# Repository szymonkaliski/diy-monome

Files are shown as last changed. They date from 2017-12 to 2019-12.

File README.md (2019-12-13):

# DIY Monome

This repo contains *some* tools for building and running DIY version of [monome](https://monome.org/) 16x8 / 8x8 grid, that's *mostly* compatible with existing monome patches and software.

There are actually three projects in this repo:
- **Neonome128** based on [Adafruit NeoTrellis boards](https://www.adafruit.com/product/3954)
- **Sparknome** which is based on four [Sparkfun PCBs](https://www.sparkfun.com/products/8033)
- **Trellinome** based on four [Adafruit Trellis boards](https://www.adafruit.com/product/1616)

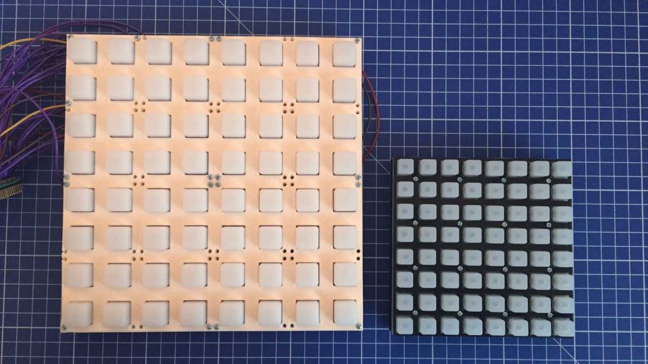
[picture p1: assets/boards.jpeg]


**Sparknome** on right, **Trellinome** on left.

These boards are not a replacement for official monome build (which is much nicer hardware), but just a DIY project.

## Neonome128

Neonome128 was built using Teensy 3.2. Build was similar to Trellinome, and I followed the official guide for soldering the boards together.

The Arduino code to drive the display is in [Neonome128](Neonome128) folder.

## Sparknome

Sparknome is based on Arduino Mega 2560 due to huge amount of digital pins used (that could be fixed with multiplexer though). I followed official [assembly guide](https://learn.sparkfun.com/tutorials/button-pad-hookup-guide), connecting four boards by joining the adjacent rows and columns. I used RGB LEDs, but wired only single colour (connecting other legs to GND), since monome doesn't support RGB.

The Arduino code to drive the display is in [Sparknome](Sparknome) folder.

## Trellinome

Trellinome was simpler to assemble than Sparknome, because there's much less wiring. It's also harder to make a mistake soldering here. I connected adjacent boards by connecting the SDA, SCL, GND, 5V and INT pins ([learn.adafruit.com/adafruit-trellis-diy-open-source-led-keypad](https://learn.adafruit.com/adafruit-trellis-diy-open-source-led-keypad)).

Since this boards require only few pins to be controlled, I could use smaller Arduino - I went with Pro Mini 5V.

The Arduino code to drive the display is in [Trellinome](Trellinome) folder.

## Arduino & Hardware & Mext

Recent Monomes use `mext` protocol to communicate OSC with serial data: [Mext Serial Codes](Mext%20Serial%20Codes.txt). Few years ago there was a "Arduinome" project, but it uses pre-mext protocol, and is not compatible with most Max/MSP patches for example. Luckily I found initial implementation made by **TheKitty**: [TheKitty/Untz_Monome](https://github.com/TheKitty/Untz_Monome) that I took as a starting point and build up on.

The official software to communicate with monomes and set up OSC server that other patches connect to is called [`serialoscd`](https://github.com/monome/serialosc). Monome detection is done through FTDI label, there are two solutions to this: either reflash Arduino FTDI chip (I didn't try that, but it's possible), or hack around this in `libmonome` code. There's folder with [patches](Patches) for both `serialosc` project (that just makes it compile on recent macOS), and a patch for `libmonome` that allowed me to detect the Arduino, and make it communicate with external software. You can get both `serialosc` and `libmonome` code from [monome github page](https://github.com/monome), and building them is well documented on official linux docs (they work for macOS as well), read part *2 Preparing your system: serialosc* (ignoring the `sudo apt-get` - I was missing `liblo`, but it's available on homebrew): [monome.org/docs/linux/](https://monome.org/docs/linux/).

I had problems with `serialoscd` that would stop responding when it was flooded with quick messages (for example famous [Meadowphysics](https://monome.org/docs/app/package/) would do that). To work around that I built my own simple nodejs based replacement (that only works with single 8x8 grid): [node-serialoscd](https://github.com/szymonkaliski/node-serialoscd). You need to `yarn install` and then run it with `node index.js /dev/tty...` (where `/dev/tty...` is mext-compatible device TTY).

The `node-serialoscd` was tested with: `Monome Home.maxpat`, `Meadowphysics.maxpat`, `re:mix` and [`node-serialosc`](https://github.com/dinchak/node-serialosc) on macOS 10.13.2.

## Case

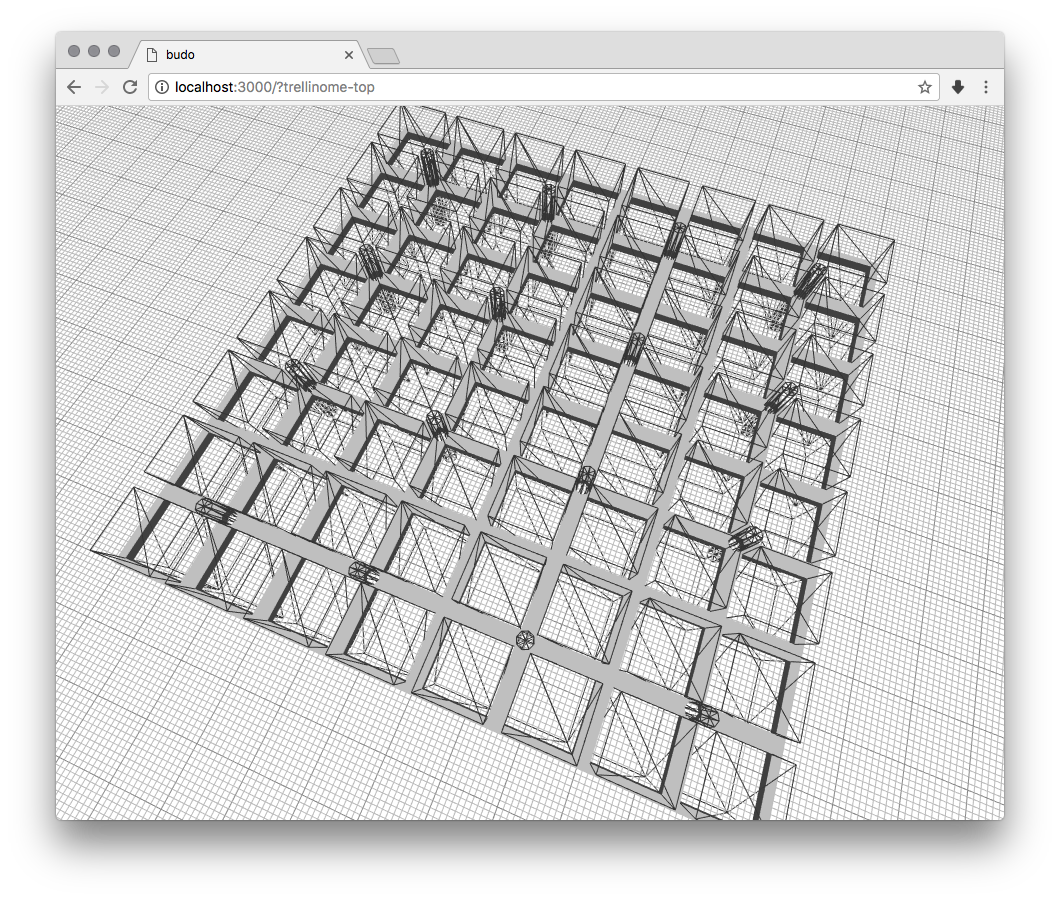
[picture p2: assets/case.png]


To complete the project I designed simple case using [@jscad/csg](https://github.com/jscad/csg.js) and [three.js](https://threejs.org), and 3D printed it. The exported STLs are part of the repo: [Case/data/](Case/data/), but you can also run the code for yourself (look at the `scripts` section of `package.json`).

The case for Neonome128 was designed in [modeler](https://github.com/szymonkaliski/modeler) and is available in [Neonome128Case](Neonome128Case) directory.

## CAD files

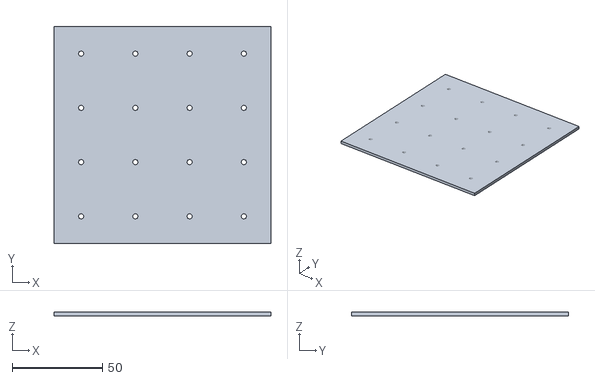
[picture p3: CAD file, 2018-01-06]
Case/data/trellinome-bottom.stl
120.0 x 120.0 x 2.00

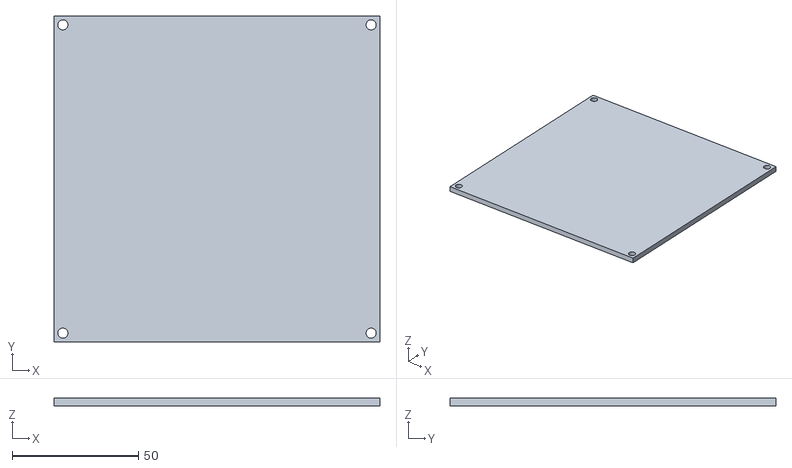
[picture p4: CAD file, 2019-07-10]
Neonome128Case/dist/case-8x8-bottom.stl
129.0 x 129.0 x 3.00

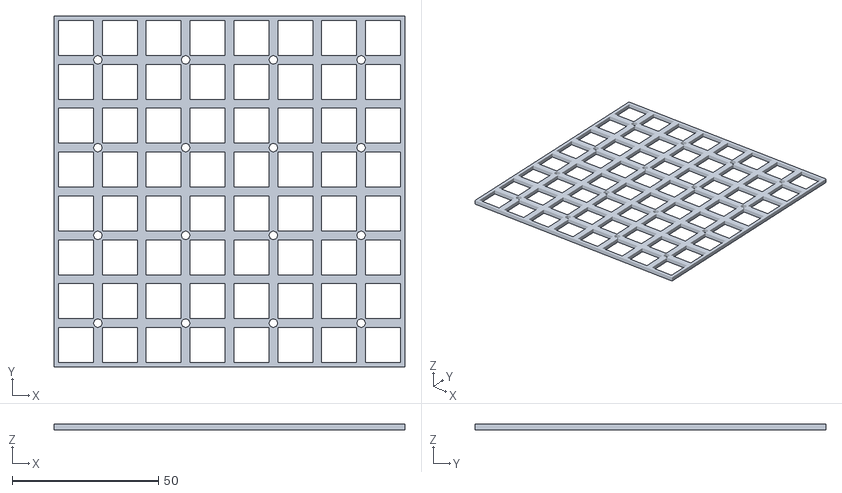
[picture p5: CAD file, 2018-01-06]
Case/data/trellinome-top.stl
120.0 x 120.0 x 2.00

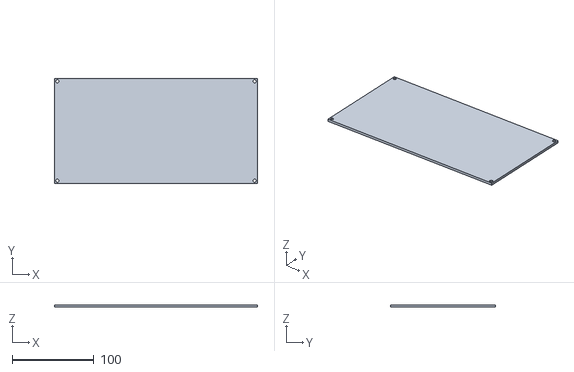
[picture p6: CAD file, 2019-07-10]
Neonome128Case/dist/case-16x8-bottom.stl
249.0 x 129.0 x 3.00

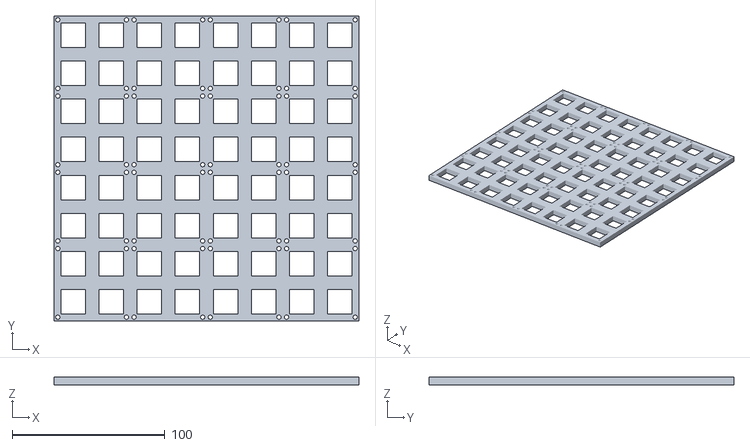
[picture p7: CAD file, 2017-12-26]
Case/data/sparknome-top.stl
200.0 x 200.0 x 5.00

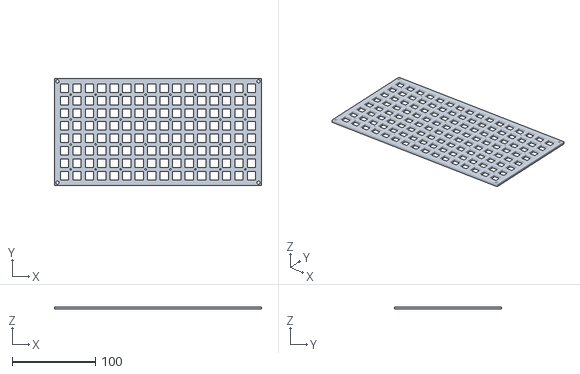
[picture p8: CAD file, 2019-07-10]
Neonome128Case/dist/case-16x8-top.stl
249.0 x 129.0 x 3.00

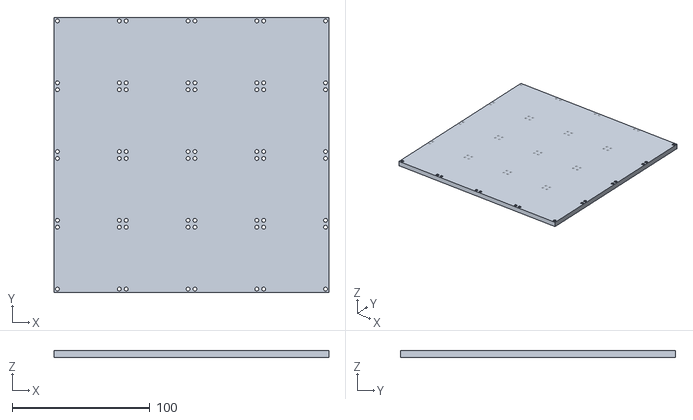
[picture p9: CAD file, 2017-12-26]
Case/data/sparknome-bottom.stl
200.0 x 200.0 x 5.00

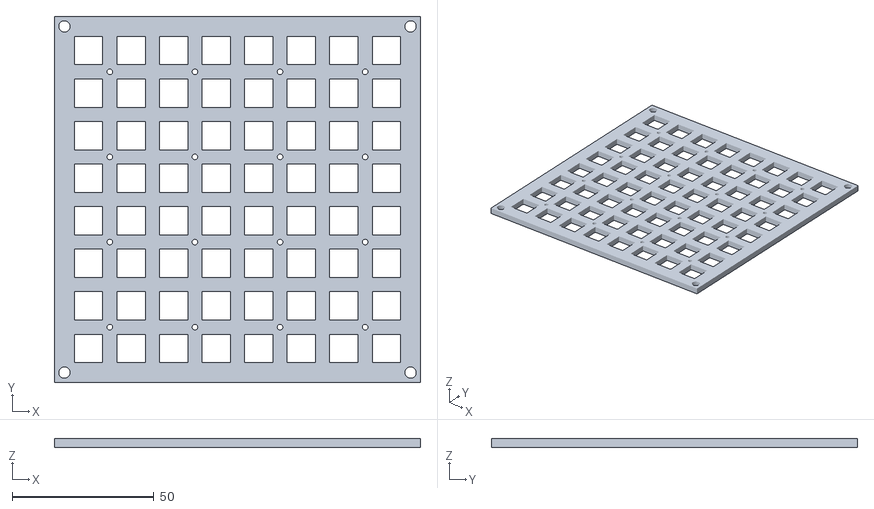
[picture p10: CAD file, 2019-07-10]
Neonome128Case/dist/case-8x8-top.stl
129.0 x 129.0 x 3.00

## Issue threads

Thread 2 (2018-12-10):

USB-Support (Question)

mbutz, 2018-12-10:
Hi,

just a question: I have an Adafruit Unztrument (Trellis based) running with an Arduino Leonardo which supports an USB connection. Do you have any plans to adapt your solution to support USB?

Martin

szymonkaliski, 2018-12-10:
Hey Martin, what do you mean by "usb support"? I'm plugging diy monome with usb cable :)

mbutz, 2018-12-10:
Hi Szymon,

thanks for the feedback and sorry for my ignorance. I am very new to the Arduino platform. I will try how far I get with your library and also use my USB cable ;)

Your solution is the only one I could find on Gitub. The Arduinome project seems to be not supported anymore.

Thanks again
Martin

Closed 2018-12-10.

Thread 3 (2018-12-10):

Error: call of overloaded 'write(int)' is ambiguous

mbutz, 2018-12-10:
Hi Szymon,

tried to compile and upload the trellis-monome library to my Adafruit Unztrument and got the following error(s). Can you help?

```
/home/marty/projects/sonicpi/arduino/code/trellis-monome/trellis-monome/trellis-monome-0.5.1/trellis-monome-0.5.1.ino: In function 'void checkButtons()':
trellis-monome-0.5.1:217: error: call of overloaded 'write(int)' is ambiguous
                Serial.write((0 << 4) | (0 & 15));
                                                ^
/home/marty/projects/sonicpi/arduino/code/trellis-monome/trellis-monome/trellis-monome-0.5.1/trellis-monome-0.5.1.ino:217:48: note: candidates are:
In file included from /home/marty/bin/arduino-1.8.5/hardware/arduino/avr/cores/arduino/Arduino.h:233:0,
                 from sketch/trellis-monome-0.5.1.ino.cpp:1:
/home/marty/bin/arduino-1.8.5/hardware/arduino/avr/cores/arduino/USBAPI.h:103:17: note: virtual size_t Serial_::write(uint8_t)
  virtual size_t write(uint8_t);
                 ^
In file included from /home/marty/bin/arduino-1.8.5/hardware/arduino/avr/cores/arduino/Stream.h:26:0,
                 from /home/marty/bin/arduino-1.8.5/hardware/arduino/avr/cores/arduino/HardwareSerial.h:29,
                 from /home/marty/bin/arduino-1.8.5/hardware/arduino/avr/cores/arduino/Arduino.h:232,
                 from sketch/trellis-monome-0.5.1.ino.cpp:1:
/home/marty/bin/arduino-1.8.5/hardware/arduino/avr/cores/arduino/Print.h:52:12: note: size_t Print::write(const char*)
     size_t write(const char *str) {
            ^
exit status 1
call of overloaded 'write(int)' is ambiguous
```

szymonkaliski, 2018-12-11:
Hm, that's strange, it seems to point to error on line 217 with `Serial.write((0 << 4) | (0 & 15));` but we don't have that line in the code:

- here's line 217: https://github.com/szymonkaliski/diy-monome/blob/master/Trellinome/Trellinome.ino#L217
- it also points to `void checkButtons()` function that again, is nowhere in this code

I just opened https://github.com/szymonkaliski/diy-monome/blob/master/Trellinome/Trellinome.ino in Arduino 1.8.7 and hit "compile" and I'm getting no errors. Keep in mind that you need the Trellis library from Adafruit.

Can you let me know bit more of what you're trying to do? Are you modyfying anything? The only thing that you should probably change is this: https://github.com/szymonkaliski/diy-monome/blob/master/Trellinome/Trellinome.ino#L93-L94

mbutz, 2018-12-11:
Hi Szymon,

well, it is not that often that I am outing myself as stupid twice in a row ;) But this time I did. Uploaded another file to my Unztrument (`trellis-monome`); to be fair to myself: It was late and I was tied.

This time everything went smoothly. But as you are so kind to answer anyway, I dare to ask for further steps. To give the context: I bought and soldered the Unztrument kit. There are two example scripts available for it: one is a simple midi pad controller script and the other a simple step sequencer. I spent some time trying to get into the programming (see if I could extend and adjust these examples) but this is kind of hard without any proper documentation and/or help. I planed to learn that much that I could (slowly but surely) program/build my own applications to control [Sonic Pi](https://github.com/samaaron/sonic-pi) with it. To get to the point:

* As I understand from your documentation I could - now that the silly mistakes are overcome - go on and try using the Unztrument with Monome applications; I am not quite sure how to go on and would be grateful if you could give some further hints (being well aware of the fact that your time is precious)
* As a first step I will have to install `serialosc`, right?
* Can I test my Unztrument running your script without MAX/MSP? (I not planning to use MAX/MSP but from some googling I understand that there is a free version which can be used for some Monome applications and I would dive into it to hopefully acquire some knowledge how I could go on).
* What should I read or do to understand what exactly I will have to look into and learn to use my new Monome-for-the-poor?
* By the way: I am on Linux

Thanks for your time
Martin

szymonkaliski, 2018-12-11:
Hey Martin,

so, Max/MSP is no-go for Linux anyways 😄
- for monome you need `serialosc`, yes; I had some problems with the official one though, so I wrote my own: https://github.com/szymonkaliski/node-serialoscd - BUT it was only tested with few apps, and I'm now using it with an app I wrote myself, so it might not be working everywhere, YMMV
- monome stuff is well documented here: https://monome.org/docs/ (you should be looking at "grid" documentation)
- most of monome apps are written in Max/MSP, but it also works with puredata (that runs on Linux), and should be pretty straightforward to run on SonicPi it it has a way to talk through OSC (afaik it does)

The way it works is:

`our fake monome <-(serial through usb cable)-> serialsc/node-serial-osc <-(osc on localhost)-> some app`

So if you want you can write your own app in whatever language you use, as long as it speaks proper OSC messages, these are documented here: https://monome.org/docs/osc/

Simplest test you could do, afaik, is probably to install my `node-serialoscd`, and run it with debug (`-d`) flag, hit some buttons and see if they log out to the console.

Keep in mind that both this hacky monome clone, and `node-serialoscd` etc. are unsupported by the original monome crew, I wrote them mainly for fun, and if I wanted something out-of-the-box I'd probably go for the original monome if I could afford it. Keeping all of that in mind, you might want to ask some questions on the monome forum as well: https://llllllll.co/

mbutz, 2018-12-11:
Wow, that was fast and provides a good starting point. Already did install `serialosc`, still figuring out how it works... thanks for giving me something to chew on!

szymonkaliski, 2018-12-11:
I'll close this issue since it's not really an issue anymore. Good luck with everything and in case of issues reach out either here, or hi@szymonkaliski.com or monome forum.

Closed 2018-12-11.

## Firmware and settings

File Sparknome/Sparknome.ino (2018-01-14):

#define NUM_LED_COLUMNS (8)
#define NUM_LED_ROWS    (8)
#define NUM_BTN_COLUMNS (8)
#define NUM_BTN_ROWS    (8)
#define NUM_KEYS        (64)
#define MAX_DEBOUNCE    (3)

static bool   ledBuffer[NUM_LED_COLUMNS][NUM_LED_ROWS];
static int8_t debounceCount[NUM_BTN_COLUMNS][NUM_BTN_ROWS];

static const uint8_t BTN_COLUMN_PIN[NUM_BTN_COLUMNS] = { 53, 51, 49, 47, 45, 43, 41, 39 };
static const uint8_t BTN_ROW_PIN[NUM_BTN_ROWS]       = { 37, 35, 33, 31, 29, 27, 25, 23 };
static const uint8_t LED_COLUMN_PIN[NUM_LED_COLUMNS] = { 52, 50, 48, 46, 44, 42, 40, 38 };
static const uint8_t LED_ROW_PIN[NUM_LED_ROWS]       = { 36, 34, 32, 30, 28, 26, 24, 22 };

uint8_t current = 0; // current matrix scan position

String deviceID  = "monome";
String serialNum = "m1000000";

static void setupPins() {
  uint8_t i, j;

  for (i = 0; i < NUM_LED_COLUMNS; i++) {
    pinMode(LED_COLUMN_PIN[i], OUTPUT);
    digitalWrite(LED_COLUMN_PIN[i], HIGH);
  }

  for (i = 0; i < NUM_BTN_COLUMNS; i++) {
    pinMode(BTN_COLUMN_PIN[i], OUTPUT);
    digitalWrite(BTN_COLUMN_PIN[i], HIGH);
  }

  for (i = 0; i < NUM_BTN_ROWS; i++) {
    pinMode(BTN_ROW_PIN[i], INPUT_PULLUP);
  }

  for (i = 0; i < NUM_LED_ROWS; i++) {
    pinMode(LED_ROW_PIN[i], OUTPUT);
    digitalWrite(LED_ROW_PIN[i], LOW);
  }

  for (i = 0; i < NUM_BTN_COLUMNS; i++) {
    for (j = 0; j < NUM_BTN_ROWS; j++) {
      debounceCount[i][j] = 0;
    }
  }
}

void setLED(int x, int y, int v) {
  if (x >= 0 && x < 8 && y >= 0 && y < 8) {
    ledBuffer[x][y] = v;
  }
}

void setAllLEDs(int value) {
  uint8_t i, j;

  for (i = 0; i < NUM_LED_COLUMNS; i++) {
    for (j = 0; j < NUM_LED_ROWS; j++) {
      ledBuffer[i][j] = value;
    }
  }
}

void turnOffLEDs() {
  setAllLEDs(0);
}

void turnOnLEDs() {
  setAllLEDs(1);
}

void setup() {
  Serial.begin(115200);

  setupPins();
  turnOffLEDs();
}

uint8_t readInt() {
  return Serial.read();
}

void writeInt(uint8_t value) {
  Serial.write(value);
}

void serialEvent() {
  do {
    processSerial();
  } while (Serial.available() > 16);
}

void processSerial() {
  uint8_t identifierSent;                     // command byte sent from controller to matrix
  uint8_t deviceAddress;                      // device address sent from controller
  uint8_t dummy;                              // for reading in data not used by the matrix
  uint8_t intensity = 255;                    // led intensity, ignored
  uint8_t readX, readY;                       // x and y values read from driver
  uint8_t i, x, y;

  identifierSent = Serial.read();             // get command identifier: first byte of packet is identifier in the form: [(a << 4) + b]
                                              // a = section (ie. system, key-grid, digital, encoder, led grid, tilt)
                                              // b = command (ie. query, enable, led, key, frame)

  switch (identifierSent) {
    case 0x00:
      writeInt((uint8_t)0x00);                // system/query response 0x00 -> 0x00
      writeInt((uint8_t)0x01);                // grids
      writeInt((uint8_t)0x01);                // one grid
      break;

    case 0x01:
      writeInt((uint8_t)0x01);
      for (i = 0; i < 32; i++) {              // has to 32
        if (i < deviceID.length()) {
          Serial.print(deviceID[i]);
        }
        else {
          Serial.print('\0');
        }
      }
      break;

    case 0x02:
      for (i = 0; i < 32; i++) {
        deviceID[i] = Serial.read();
      }
      break;

    case 0x03:
      writeInt((uint8_t)0x02);                // system / request grid offsets
      // writeInt(0);                         // n grid?
      writeInt((uint8_t)0x00);                // x offset
      writeInt((uint8_t)0x00);                // y offset
      break;

    case 0x04:
      dummy = readInt();                      // system / set grid offset
      readX = readInt();                      // an offset of 8 is valid only for 16 x 8 monome
      readY = readInt();                      // an offset is invalid for y as it's only 8
      break;

    case 0x05:
      writeInt((uint8_t)0x03);                // system / request grid size
      writeInt((uint8_t)8);
      writeInt((uint8_t)8);
      break;

    case 0x06:
      readX = readInt();                      // system / set grid size - ignored
      readY = readInt();
      break;

    case 0x07:
      break;                                  // I2C stuff - ignored

    case 0x08:
      deviceAddress = readInt();              // set addr - ignored
      dummy = readInt();
      break;

    case 0x0F:
      writeInt((uint8_t)0x0F);                // send serial number
      Serial.print(serialNum);
      break;

    case 0x10:
      readX = readInt();
      readY = readInt();
      setLED(readX, readY, 0);
      break;

    case 0x11:
      readX = readInt();
      readY = readInt();
      setLED(readX, readY, 1);
      break;

    case 0x12:
      turnOffLEDs();
      break;

    case 0x13:
      turnOnLEDs();
      break;

    case 0x14:
      readX = readInt();
      readY = readInt();

      if (readX == 8 && NUM_KEYS > 64) break; // trying to set an 8x16 grid on a pad with only 64 keys
      if (readY != 0) break;                  // since we only have 8 LEDs in a column, no offset

      for (y = 0; y < 8; y++) {               // each i will be a row
        intensity = readInt();                // read one byte of 8 bits on/off
        for (x = 0; x < 8; x++) {             // for 8 LEDs on a row
          if ((intensity >>x ) & 0x01) {      // set LED if the intensity bit is set
            setLED(readX + x, y, 1);
          }
          else {
            setLED(readX + x, y, 0);
          }
        }
      }
      break;

    case 0x15:
      readX = readInt();                      // led-grid / set row
      readY = readInt();                      // may be any value
      intensity = readInt();                  // read one byte of 8 bits on/off

      for (i = 0; i < 8; i++) {               // for the next 8 lights in row
        if ((intensity >> i) & 0x01) {        // if intensity bit set, light
          setLED(readX + i, readY, 1);
        }
        else {
          setLED(readX + i, readY, 0);
        }
      }
      break;

    case 0x16:
      readX = readInt();                      // led-grid / column set
      readY = readInt();

      intensity = readInt();                  // read one byte of 8 bits on/off
      if (readY != 0) break;                  // we only have 8 lights in a column

      for (i = 0; i < 8; i++) {               // for the next 8 lights in column
        if ((intensity >> i) & 0x01) {        // if intensity bit set, light
          setLED(readX, i, 1);
        }
        else {
          setLED(readX, i, 0);
        }
      }
      break;

    case 0x17:
      intensity = readInt();                  // intensity stuff - ignored
      break;

    case 0x18:
      readX = readInt();                      // led-grid / set LED intensity
      readY = readInt();                      // read the x and y coordinates
      intensity = readInt();                  // read the intensity value (0-255, 0x00-0xFF)

      if (intensity > 0) {
        setLED(readX, readY, 1);
      }
      else {
        setLED(readX, readY, 0);
      }
      break;

    case 0x19:                                // set all leds
      intensity = readInt();

      if (intensity > 0) {
        turnOnLEDs();
      }
      else {
        turnOffLEDs();
      }

    case 0x1A:                                // set 8x8 block
      readX = readInt();
      readY = readInt();

      for (y = 0; y < 8; y++) {
        for (x = 0; x < 8; x++) {
          if ((x + y) % 2 == 0) {             // even bytes, use upper nybble
            intensity = readInt();

            if (intensity >> 4 & 0x0F)  {
              setLED(readX + x, y, 1);
            }
            else {
              setLED(readX + x, y, 0);
            }
          }
          else {                              // odd bytes, use lower nybble
            if (intensity & 0x0F) {
              setLED(readX + x, y, 1);
            }
            else {
              setLED(readX + x, y, 0);
            }
          }
        }
      }
      break;

    case 0x1B:                                // set 8x1 row by intensity
      readX = readInt();
      readY = readInt();

      for (x = 0; x < 8; x++) {
        intensity = readInt();

        if (intensity) {
          setLED(readX + x, readY, 1);
        }
      }
      break;

    case 0x1C:                                // set 1x8 column by intensity
      readX = readInt();
      readY = readInt();

      for (y = 0; y < 8; y++) {
        intensity = readInt();

        if (intensity) {
          setLED(readX, readY + y, 1);
        }
      }
      break;

    default:
      break;
  }

  return;
}

static void scanMatrix(int current) {
  uint8_t btnVal, i, j;

  // select current columns
  digitalWrite(BTN_COLUMN_PIN[current], LOW);
  digitalWrite(LED_COLUMN_PIN[current], LOW);

  // output LED row values
  for (i = 0; i < NUM_LED_ROWS; i++) {
    if (ledBuffer[current][i] > 0) {
      digitalWrite(LED_ROW_PIN[i], HIGH);
    }
  }

  delay(1);

  // read the button inputs
   for (j = 0; j < NUM_BTN_ROWS; j++) {
     btnVal = digitalRead(BTN_ROW_PIN[j]);

     if (btnVal == LOW) {
       // button pressed
       if (debounceCount[current][j] < MAX_DEBOUNCE) {
         debounceCount[current][j]++;

         if (debounceCount[current][j] == MAX_DEBOUNCE) {
           // send button coords
           Serial.write(0x21);
           Serial.write(current);
           Serial.write(j);
         }
       }
     }
     else {
       // button released
       if (debounceCount[current][j] > 0) {
         debounceCount[current][j]--;

         if (debounceCount[current][j] == 0) {
           // send button coords
           Serial.write(0x20);
           Serial.write(current);
           Serial.write(j);
         }
       }
     }
   }

  delay(1);

  digitalWrite(BTN_COLUMN_PIN[current], HIGH);
  digitalWrite(LED_COLUMN_PIN[current], HIGH);

  for (i = 0; i < NUM_LED_ROWS; i++) {
    digitalWrite(LED_ROW_PIN[i], LOW);
  }
}

void loop() {
  scanMatrix(current);

  current++;
  if (current >= NUM_LED_COLUMNS) {
    current = 0;
  }
}

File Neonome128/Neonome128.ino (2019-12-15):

#include <Adafruit_NeoTrellis.h>

#define DIM_X 16
#define DIM_Y 8

#define INT_PIN 4
#define LED_PIN 13 // internal LED used to show boot info

#define BRIGHTNESS 100
#define R 255
#define G 255
#define B 255

Adafruit_NeoTrellis trellis_parts[DIM_Y / 4][DIM_X / 4] = {
    {Adafruit_NeoTrellis(0x31), Adafruit_NeoTrellis(0x30),
     Adafruit_NeoTrellis(0x2F), Adafruit_NeoTrellis(0x2E)},
    {Adafruit_NeoTrellis(0x35), Adafruit_NeoTrellis(0x34),
     Adafruit_NeoTrellis(0x33), Adafruit_NeoTrellis(0x32)}};

Adafruit_MultiTrellis trellis((Adafruit_NeoTrellis *)trellis_parts, DIM_Y / 4,
                              DIM_X / 4);

String deviceID = "neonome";
String serialNum = "m4676000";

uint8_t ledBuffer[DIM_X * DIM_Y];
uint8_t prevLedBuffer[DIM_X * DIM_Y];
bool isInited = false;

elapsedMillis refreshTime;

void setLED(uint8_t x, uint8_t y, uint8_t value) {
  // sanity check, but it was killing teensy looks like norns by default sends
  // offsets for 256, so we're ignoring values outside of available dimensions
  if (x >= DIM_X || y >= DIM_Y) {
    return;
  }

  int index = x + (y << 4);
  ledBuffer[index] = value;
}

void setAllLEDs(uint8_t value) {
  uint8_t x, y;

  for (x = 0; x < DIM_X; x++) {
    for (y = 0; y < DIM_Y; y++) {
      setLED(x, y, value);
    }
  }
}

void turnOffLEDs() { setAllLEDs(0); }

void turnOnLEDs() { setAllLEDs(15); }

TrellisCallback keyCallback(keyEvent evt) {
  uint8_t x = evt.bit.NUM % DIM_X;
  uint8_t y = evt.bit.NUM / DIM_X;

  if (evt.bit.EDGE == SEESAW_KEYPAD_EDGE_FALLING) {
    Serial.write(0x20);
  } else {
    Serial.write(0x21);
  }

  Serial.write(x);
  Serial.write(y);

  return 0;
}

void setup() {
  Serial.begin(115200);

  pinMode(INT_PIN, INPUT);

  pinMode(LED_PIN, OUTPUT);
  digitalWrite(LED_PIN, HIGH);
}

void processSerial() {
  uint8_t identifierSent; // command byte sent from controller to matrix
  uint8_t intensity = 15; // led intensity
  uint8_t readX, readY;   // x and y values read from driver
  uint8_t i, x, y, z;

  // get command identifier: first byte of packet is identifier in the form:
  // [(a << 4) + b]
  // a = section (ie. system, key-grid, digital, encoder, led grid, tilt)
  // b = command (ie. query, enable, led, key, frame)
  identifierSent = Serial.read();

  switch (identifierSent) {
  case 0x00:
    Serial.write(0x00); // system/query response 0x00 -> 0x00
    Serial.write(0x01); // grids
    Serial.write(0x01); // one grid
    break;

  case 0x01:
    Serial.write(0x01);
    for (i = 0; i < 32; i++) { // has to be 32
      if (i < deviceID.length()) {
        Serial.write(deviceID[i]);
      } else {
        Serial.write(0x00);
      }
    }
    break;

  case 0x02:
    for (i = 0; i < 32; i++) {
      deviceID[i] = Serial.read();
    }
    break;

  case 0x03:
    Serial.write(0x02); // system / request grid offsets
    Serial.write(0x01); // n number
    Serial.write(0);    // x offset
    Serial.write(0);    // y offset
    break;

  case 0x04:
    Serial.read(); // system / set grid offset
    Serial.read(); // grid number
    Serial.read(); // x offset
    Serial.read(); // y offset
    break;

  case 0x05:
    Serial.write(0x03); // system / request grid size
    Serial.write(DIM_X);
    Serial.write(DIM_Y);
    break;

  case 0x06:
    // set grid size
    Serial.read(); // size x
    Serial.read(); // size y
    break;

  case 0x07:
    // get ADDR (I2C)
    break;

  case 0x08:
    // set ADDR (I2C)
    Serial.read(); // addr to set
    Serial.read(); // new addr value
    break;

  case 0x0F:
    Serial.write(0x0F);       // send serial number
    for (i = 0; i < 8; i++) { // has to be 8
      if (i < serialNum.length()) {
        Serial.write(serialNum[i]);
      } else {
        Serial.write(0x00);
      }
    }
    break;

  case 0x10:
    readX = Serial.read();
    readY = Serial.read();
    setLED(readX, readY, 0);
    break;

  case 0x11:
    readX = Serial.read();
    readY = Serial.read();
    setLED(readX, readY, 15);
    break;

  case 0x12:
    turnOffLEDs();
    break;

  case 0x13:
    turnOnLEDs();
    break;

  case 0x14:
    readX = Serial.read();
    readY = Serial.read();

    for (y = 0; y < 8; y++) {    // each i will be a row
      intensity = Serial.read(); // read one byte of 8 bits on/off

      for (x = 0; x < 8; x++) { // for 8 LEDs on a row
        setLED(readX + x, y, intensity);
      }
    }
    break;

  case 0x15:
    readX = Serial.read(); // led-grid / set row
    readY = Serial.read(); // may be any value

    intensity = Serial.read(); // read one byte of 8 bits on/off

    for (x = 0; x < 8; x++) {        // for the next 8 lights in row
      if ((intensity >> x) & 0x01) { // if intensity bit set, light led
        setLED(readX + x, readY, intensity);
      } else {
        setLED(readX + x, readY, 0);
      }
    }
    break;

  case 0x16:
    readX = Serial.read(); // led-grid / column set
    readY = Serial.read();

    intensity = Serial.read(); // read one byte of 8 bits on/off

    for (y = 0; y < 8; y++) {        // for the next 8 lights in column
      if ((intensity >> y) & 0x01) { // if intensity bit set, light led
        setLED(readX, readY + y, intensity);
      } else {
        setLED(readX, readY + y, 0);
      }
    }
    break;

  case 0x17:
    // intensity for entire grid - ignored
    Serial.read();
    break;

  case 0x18:
    readX = Serial.read();     // led-grid / set LED intensity
    readY = Serial.read();     // read the x and y coordinates
    intensity = Serial.read(); // read the intensity value (0-255)

    setLED(readX, readY, intensity);
    break;

  case 0x19: // set all leds
    intensity = Serial.read();
    setAllLEDs(intensity);
    break;

  case 0x1A: // set 8x8 block
    readX = Serial.read();
    readY = Serial.read();

    z = 0;

    for (y = 0; y < 8; y++) {
      for (x = 0; x < 8; x++) {
        if (z % 2 == 0) {
          // even bytes, read value and use upper nybble
          intensity = Serial.read();

          setLED(readX + x, readY + y, (intensity >> 4 & 0x0F));
        } else {
          // odd bytes, use lower nybble
          setLED(readX + x, readY + y, (intensity & 0x0F));
        }

        z++;
      }
    }
    break;

  case 0x1B: // set 8x1 row by intensity
    readX = Serial.read();
    readY = Serial.read();

    for (x = 0; x < 8; x++) {
      if (x % 2 == 0) {
        // even bytes, read value and use upper nybble
        intensity = Serial.read();

        setLED(readX + x, readY, (intensity >> 4 & 0x0F));
      } else {
        // odd bytes, use lower nybble
        setLED(readX + x, readY, (intensity & 0x0F));
      }
    }
    break;

  case 0x1C: // set 1x8 column by intensity
    readX = Serial.read();
    readY = Serial.read();

    for (y = 0; y < 8; y++) {
      if (y % 2 == 0) {
        // even bytes, read value and use upper nybble
        intensity = Serial.read();
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

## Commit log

2017-12-17 basic case with better preview
2017-12-18 initial case finished
2017-12-18 STL export
    [monome-case.stl]
2017-12-18 stl + gcode
    [monome-case.stl]
2017-12-19 export model with proper dimensions
    [monome-case.stl]
2017-12-23 working monome mext protocol on arduino mega with four sparkfun 4x4 grids
2017-12-26 export different case files
    [sparknome-top.stl]
2017-12-26 sparknome top+bottom
    [sparknome-bottom.stl, sparknome-top.stl]
2018-01-06 intial trellinome casing
    [trellinome-bottom.stl, trellinome-top.stl]
2018-01-14 updated arduino files
2019-07-03 new cases
    [case-16x8-bottom.stl, case-16x8-top.stl, case-8x8-bottom.stl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]
2019-07-10 model fixes
    [case-16x8-bottom.stl, case-16x8-top.stl, case-8x8-bottom.stl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]
2019-10-07 README update
    [case-16x8-bottom.stl, case-16x8-top.stl, case-8x8-bottom.stl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]
